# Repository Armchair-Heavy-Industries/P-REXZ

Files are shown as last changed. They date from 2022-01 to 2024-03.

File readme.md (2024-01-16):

# P-REXZ
The P-REXZ is a cantilevered CoreXZ 3D Printer with a polar bed. 

The current state of the project is as follows:
Mechanically, the printer is functional and prints. Currently honing in printability and ease of assembly. A more capable Polar/PolarXZ kinematic type has been added to klipper, and optimization still needs to be done.

Project Leads: Derpimus, Corvid, and Bwnance

Join me on Discord (https://discord.gg/armchairengineeringsux)

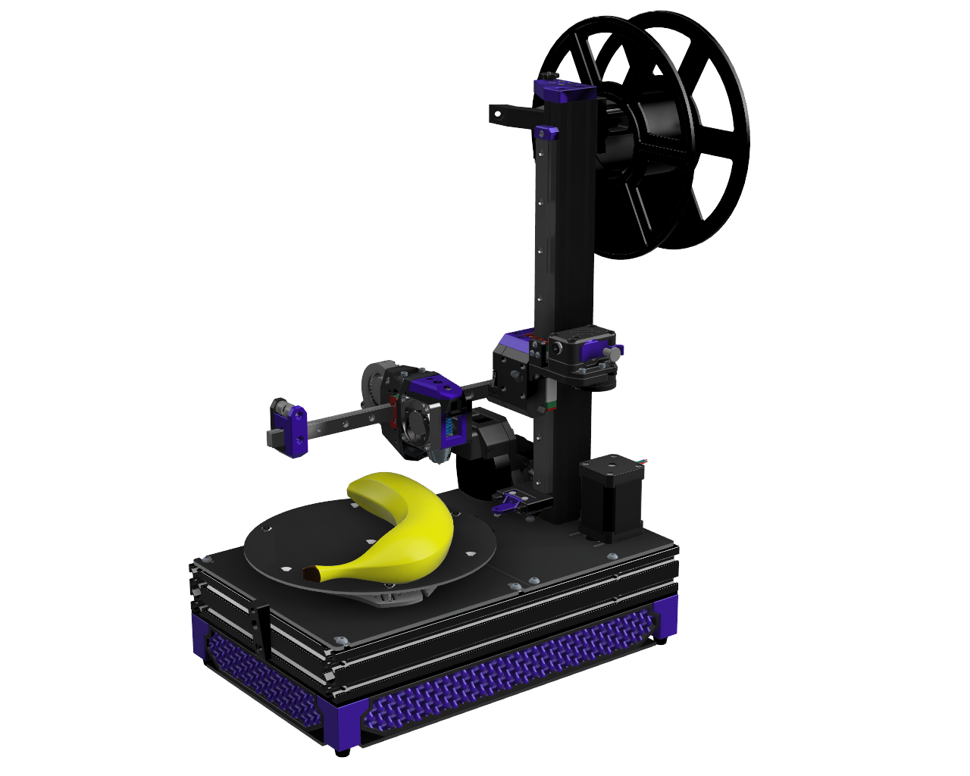
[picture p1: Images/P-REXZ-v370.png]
Image of the P-REXZ


Thank you for T-Laser for the belt path inspiration https://github.com/FiCacador/Tlaser

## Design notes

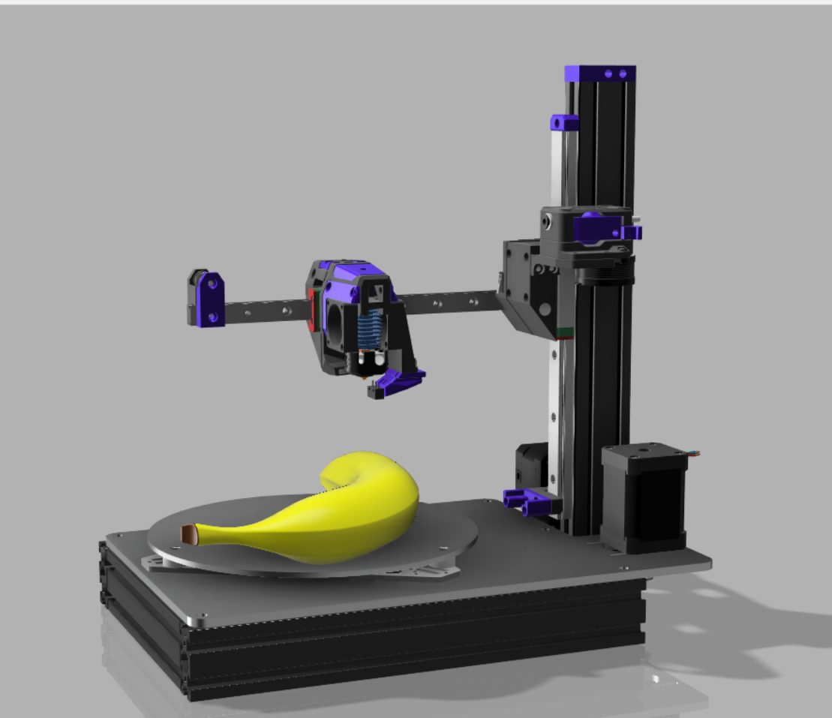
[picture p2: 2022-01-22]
Images/PREXZ.png

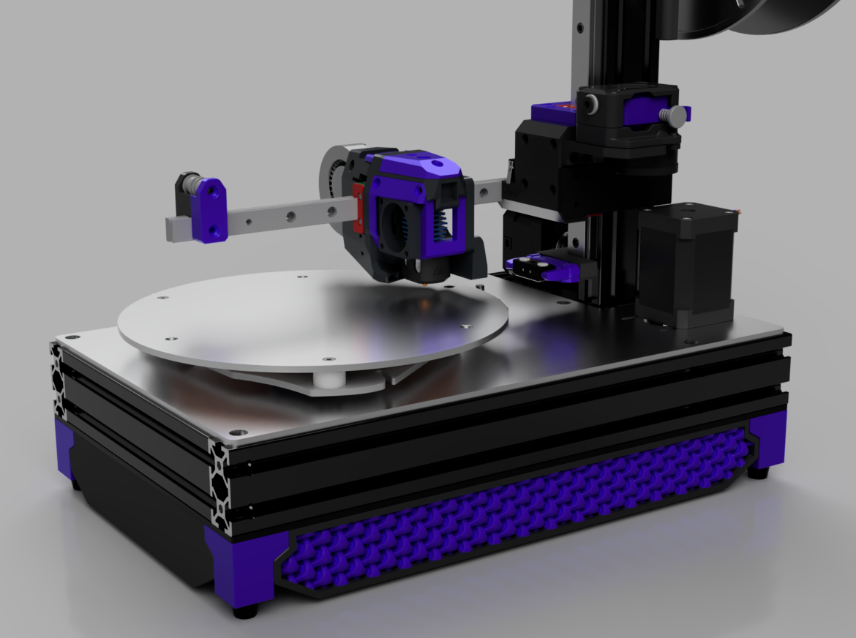
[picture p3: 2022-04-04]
Images/P-REXZ-V247.png

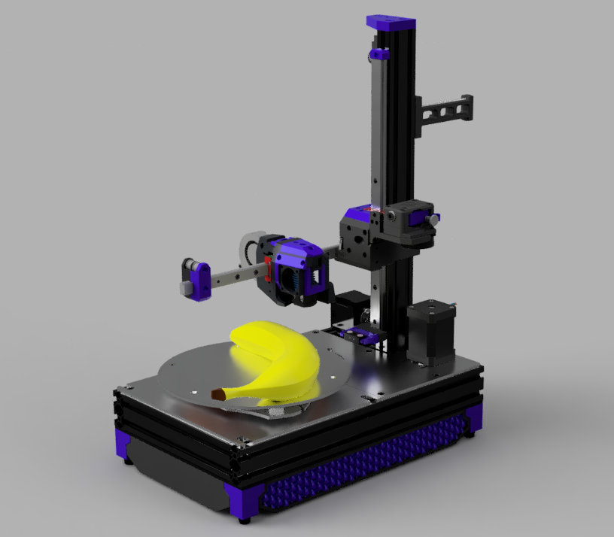
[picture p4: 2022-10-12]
Images/P-REXZ-V274.png

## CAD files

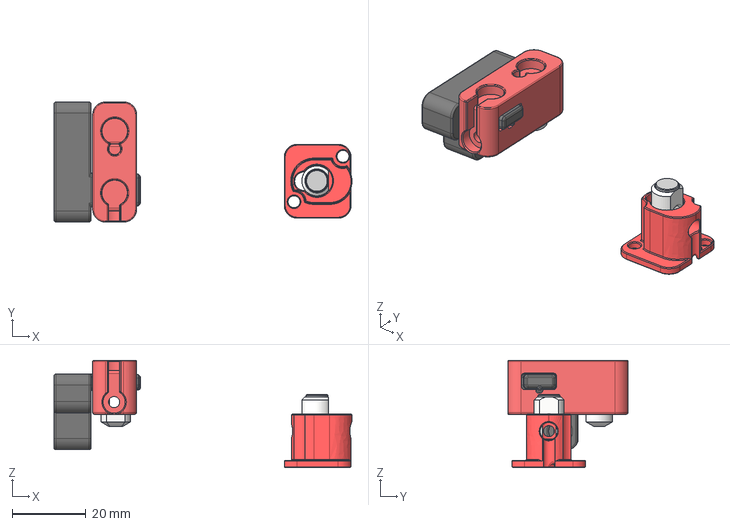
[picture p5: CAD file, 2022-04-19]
CAD/Prexz unklicky 01 v1.step
80.6 x 32.5 x 29.0 mm
Probe Dock v2
z endstop

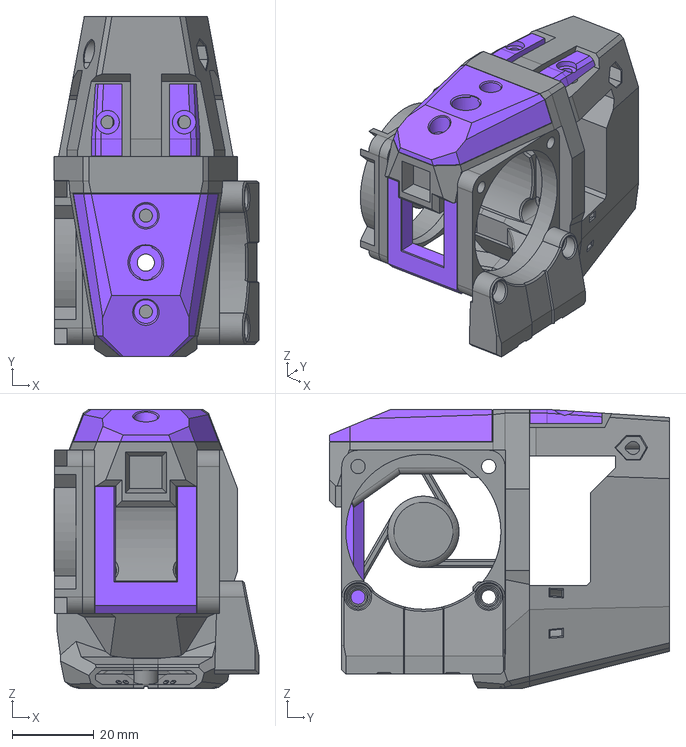
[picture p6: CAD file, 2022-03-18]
CAD/Toolhead/Toolhead V1 - Rapido.step
50.2 x 83.3 x 68.4 mm

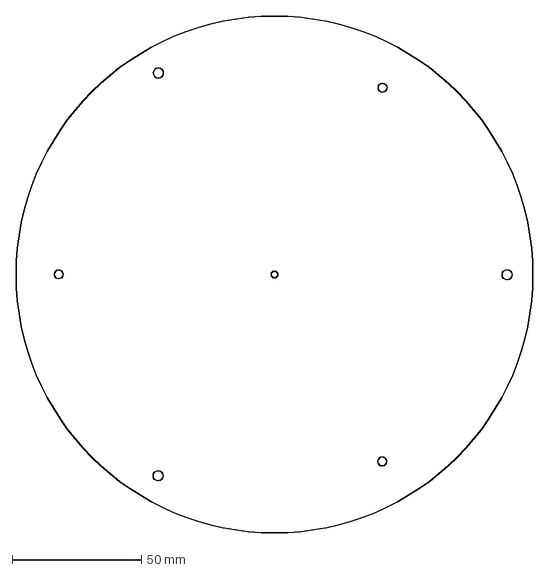
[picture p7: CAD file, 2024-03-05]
DXF+Drawings/Bed/Bed.dxf
200.0 x 200.0 mm

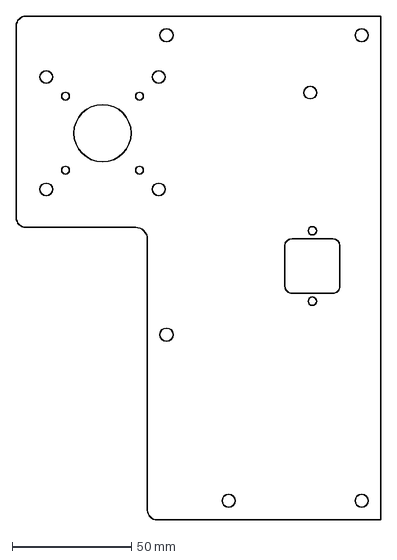
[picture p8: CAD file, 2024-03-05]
DXF+Drawings/BedPlates/BedPlate2.dxf
152.7 x 211.0 mm

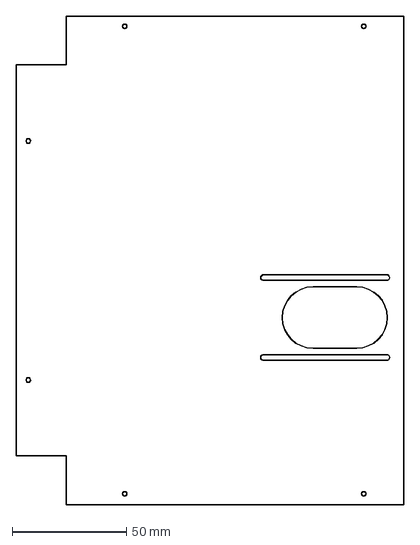
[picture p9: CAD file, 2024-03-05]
DXF+Drawings/ElectronicsPlates/LowerElectronicsPlate1.dxf
169.7 x 214.2 mm

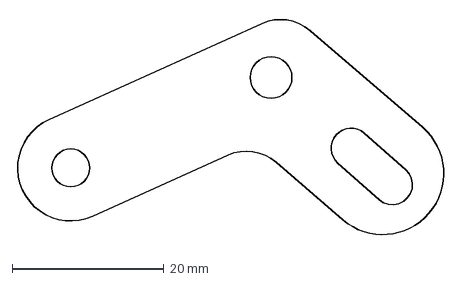
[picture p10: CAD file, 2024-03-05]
DXF+Drawings/Frame+misc/TensionerBone[x2].dxf
57.4 x 29.8 mm

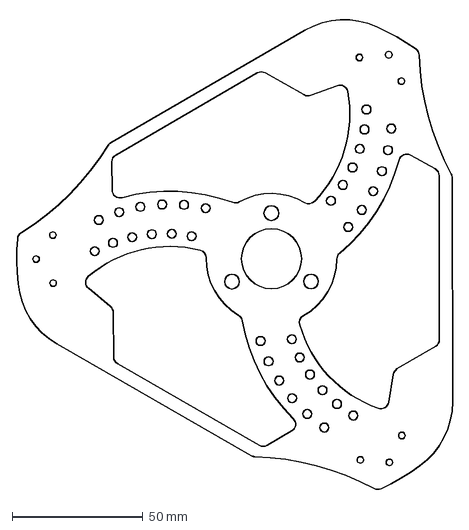
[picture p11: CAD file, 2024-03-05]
DXF+Drawings/Mallninja/MallNinja.dxf
166.8 x 181.1 mm

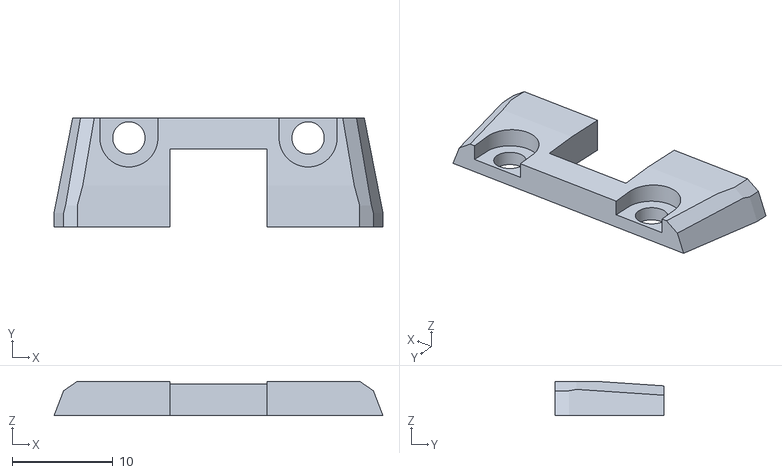
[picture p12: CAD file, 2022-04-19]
STLs/Toolhead/Dragonfly BMO/[a]_V1 - UniClamp.stl
32.6 x 10.8 x 3.40

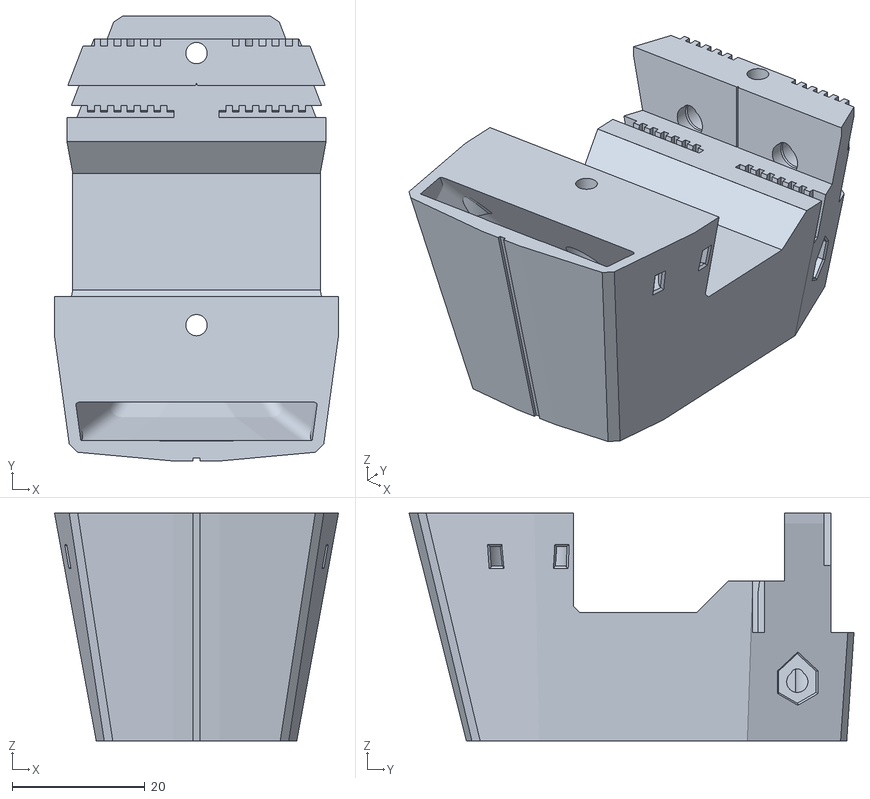
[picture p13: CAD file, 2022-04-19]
STLs/Toolhead/Rapido/V1 - Print Fan Mount.stl
42.8 x 67.0 x 34.3

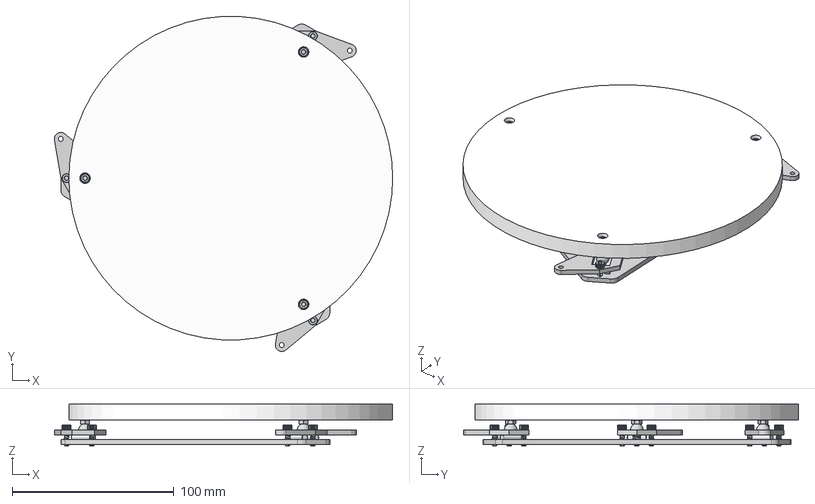
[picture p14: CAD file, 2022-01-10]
CAD/Mall Ninja Bed.step
209.0 x 206.9 x 25.9 mm
91292A114_18-8 Stainless Steel Socket Head Screw x 3
90592A085_Steel Hex Nut x 3
1598K29_Hardened Bearing-Quality 440C Stainless Steel Ball x 3
4mm diameter rod x 6
90751A112_18-8 Stainless Steel Socket Head Screws x 9

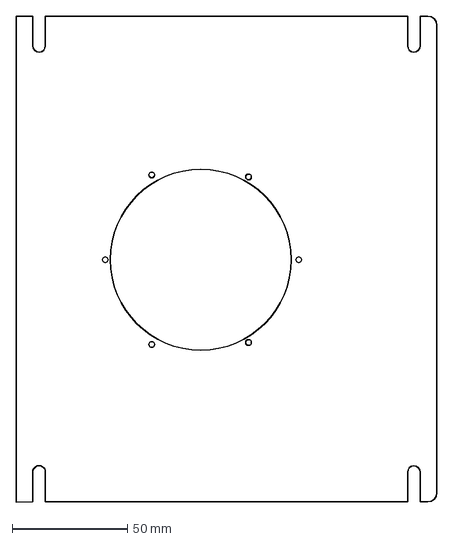
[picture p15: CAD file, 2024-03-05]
DXF+Drawings/BedPlates/BedPlate1.dxf
182.8 x 211.0 mm

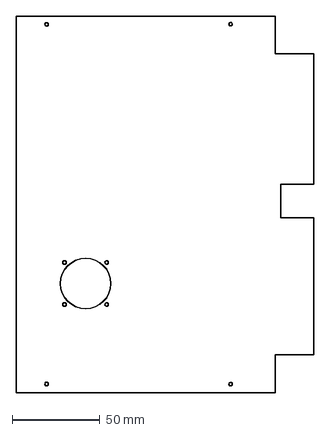
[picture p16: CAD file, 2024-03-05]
DXF+Drawings/ElectronicsPlates/LowerElectronicsPlate2.dxf
169.7 x 214.2 mm

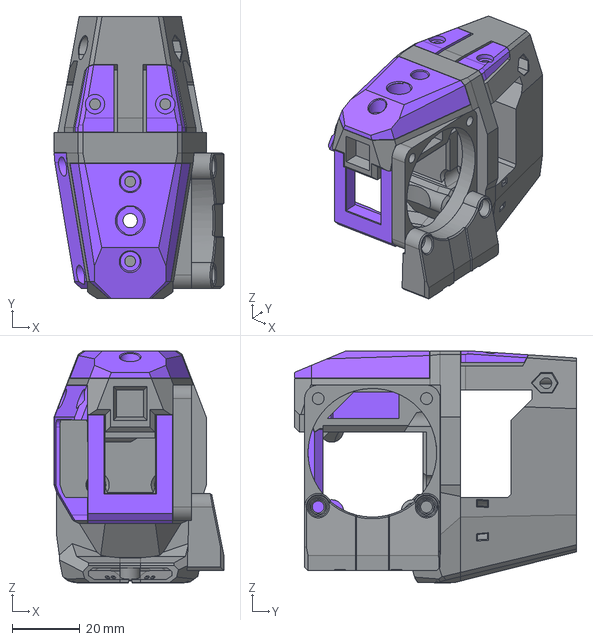
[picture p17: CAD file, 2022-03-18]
CAD/Toolhead/Toolhead V1 - Dragonfly BMO.step
50.2 x 83.3 x 68.4 mm

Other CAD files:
CAD/Toolhead/Toolhead V1 - Revo.step
DXF+Drawings/ElectronicsPlates/UpperElectronicsPlate.dxf
STLs/Toolhead/Dragonfly BMO/V1 - 4007 Grill.stl
STLs/Toolhead/Dragonfly BMO/V1 - Air Guide-Face - 3010.stl
STLs/Toolhead/Dragonfly BMO/V1 - Dragonfly BMO - Hotend Mount.stl
STLs/Toolhead/Dragonfly BMO/V1 - Klicky Mount.stl
STLs/Toolhead/Dragonfly BMO/[a]_V1 - 3010 Speed Fairing.stl
STLs/Toolhead/Dragonfly BMO/[a]_V1 - DD Mount Cap.stl
STLs/Toolhead/Rapido/V1 - 4007 Fan - 3mm Spacer.stl
STLs/Toolhead/Rapido/V1 - 4007 Grill.stl
STLs/Toolhead/Rapido/V1 - Klicky Mount.stl
STLs/Toolhead/Rapido/V1 - Rapido - Hotend Mount - V1.stl
STLs/Toolhead/Rapido/[a]_ V1 - DD Mount Cap.stl
STLs/Toolhead/Rapido/[a]_Rapido - V1 - Air Guide-Face.stl
STLs/Toolhead/Revo/V1 - 4007 Grill.stl
STLs/Toolhead/Revo/V1 - Air Guide-Face - 3010.stl
STLs/Toolhead/Revo/V1 - Klicky Mount.stl
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

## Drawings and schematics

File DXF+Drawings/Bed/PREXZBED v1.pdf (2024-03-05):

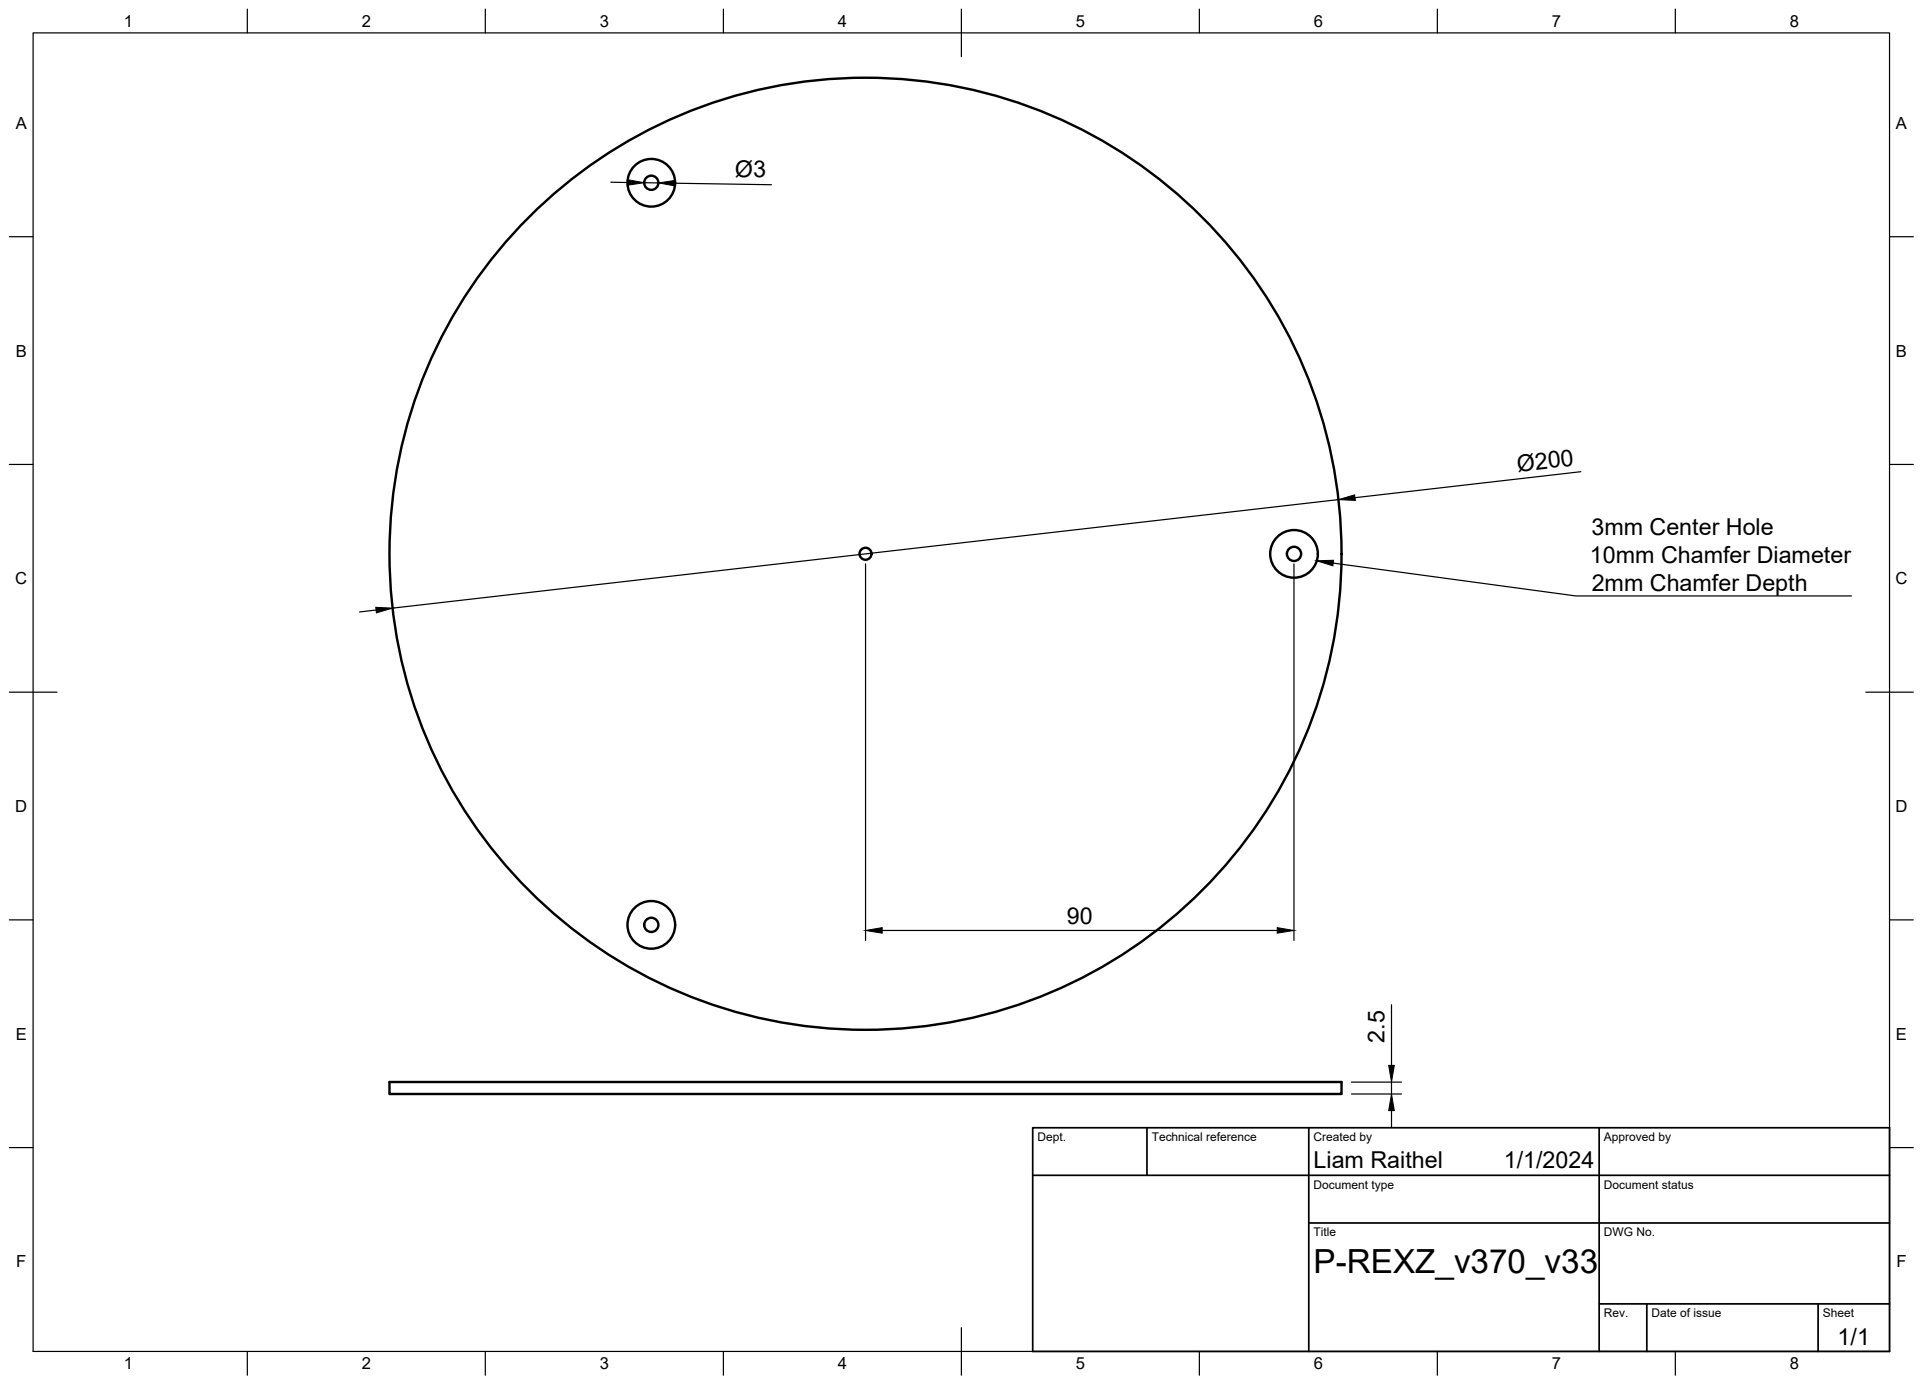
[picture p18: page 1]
Title; DWG No.; Rev.; Date of issue; Sheet; Liam Raithel 2.5; 3mm Center Hole 10mm Chamfer Diameter 2mm Chamfer Depth

Dept. | Technical reference | Created by 1/1/2024 | Approved by

Document type | Document status

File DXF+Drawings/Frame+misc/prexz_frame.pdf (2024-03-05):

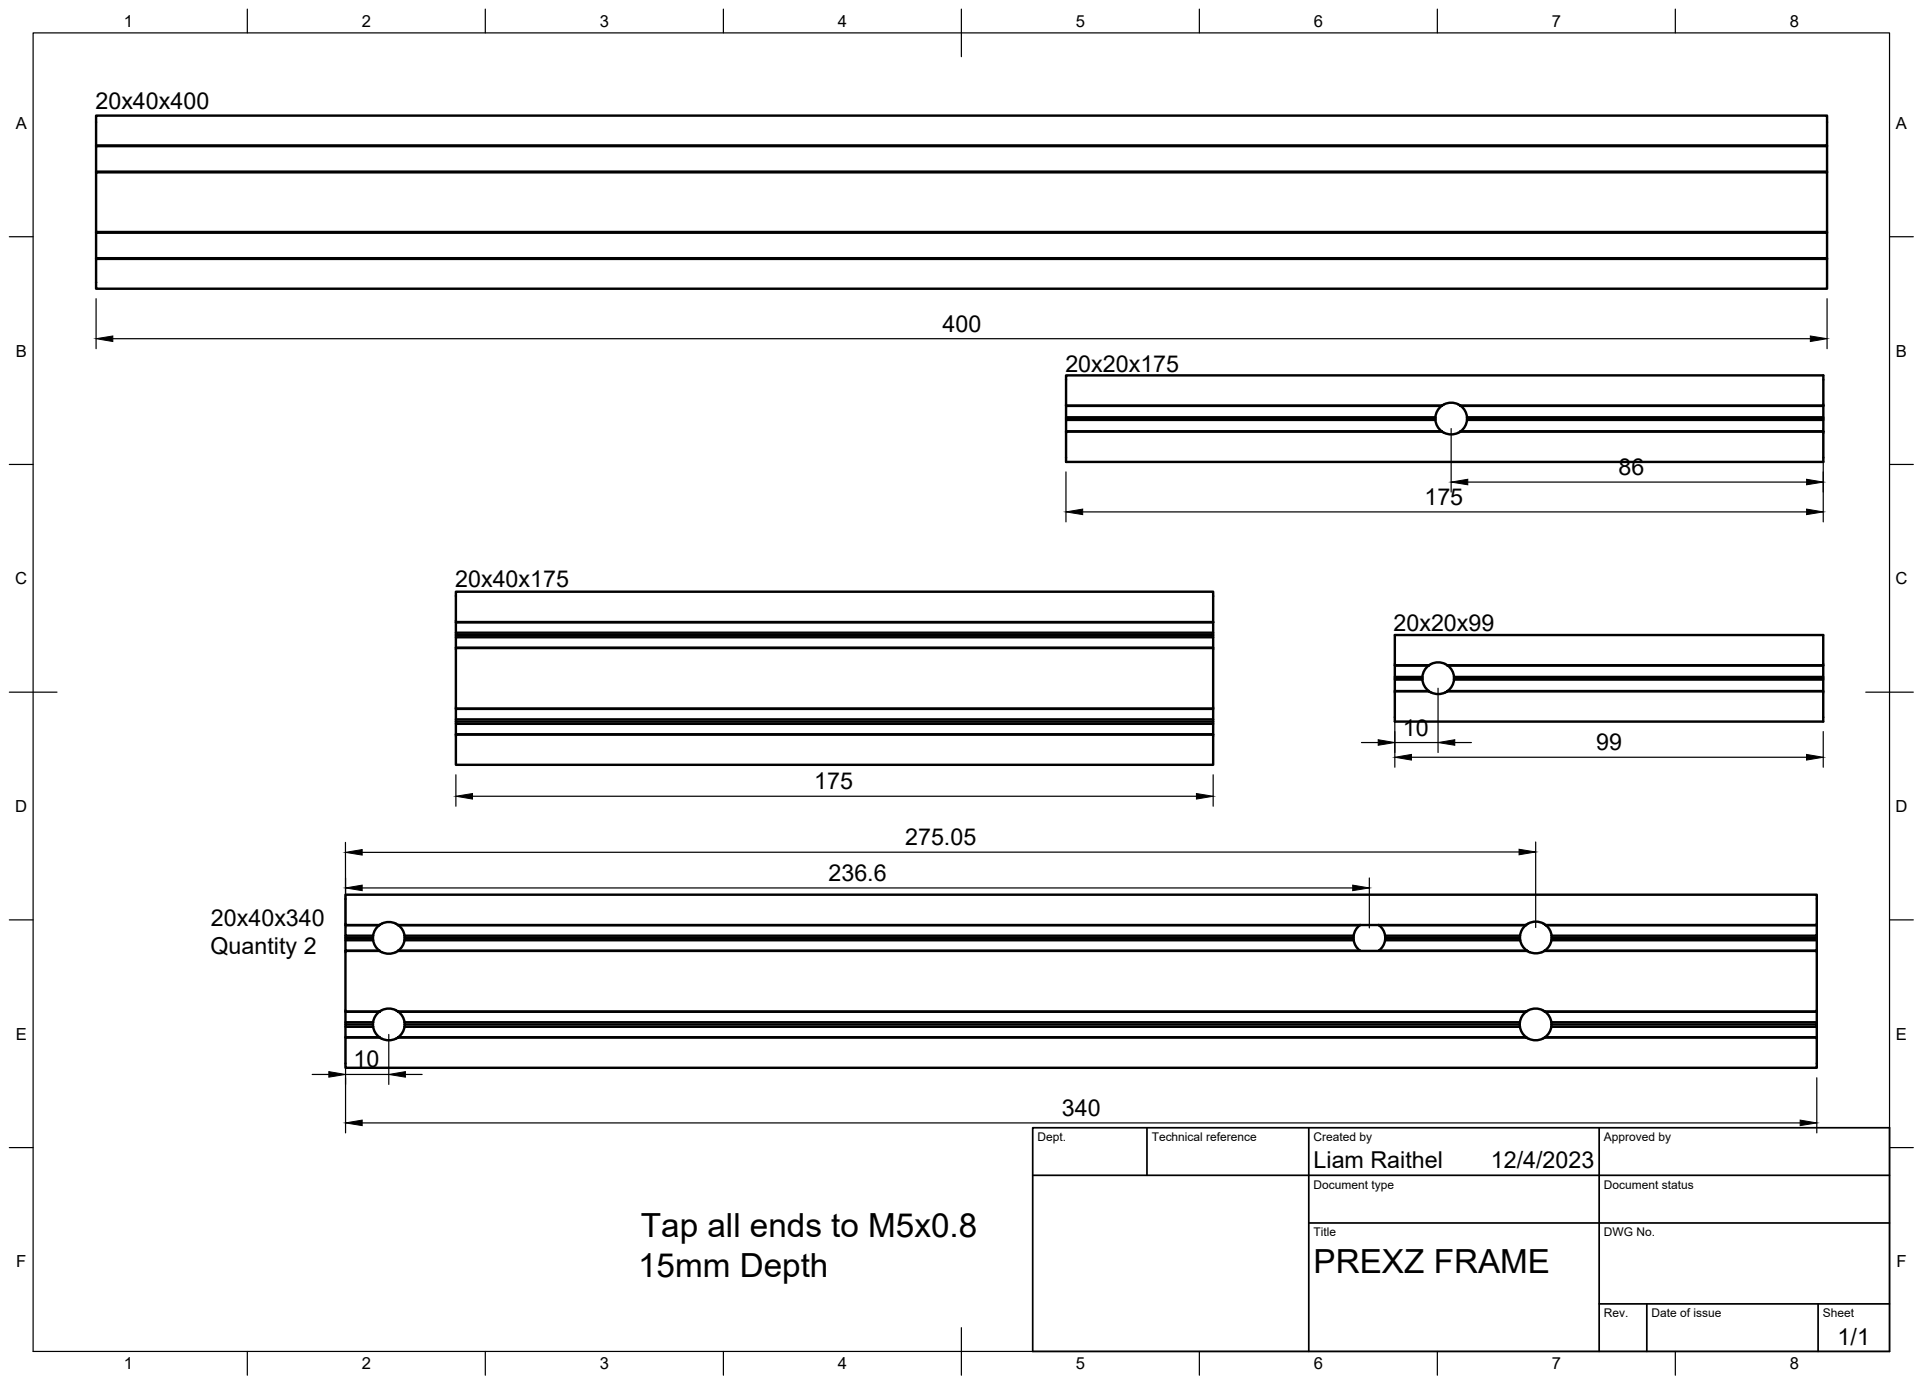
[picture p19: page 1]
Title; DWG No.; Rev.; Date of issue; Sheet; PREXZ FRAME; Quantity 2

Dept. | Technical reference | Created by Liam Raithel 12/4/2023 | Approved by

Document type | Document status

Tap all ends to M5x0.8
15mm Depth

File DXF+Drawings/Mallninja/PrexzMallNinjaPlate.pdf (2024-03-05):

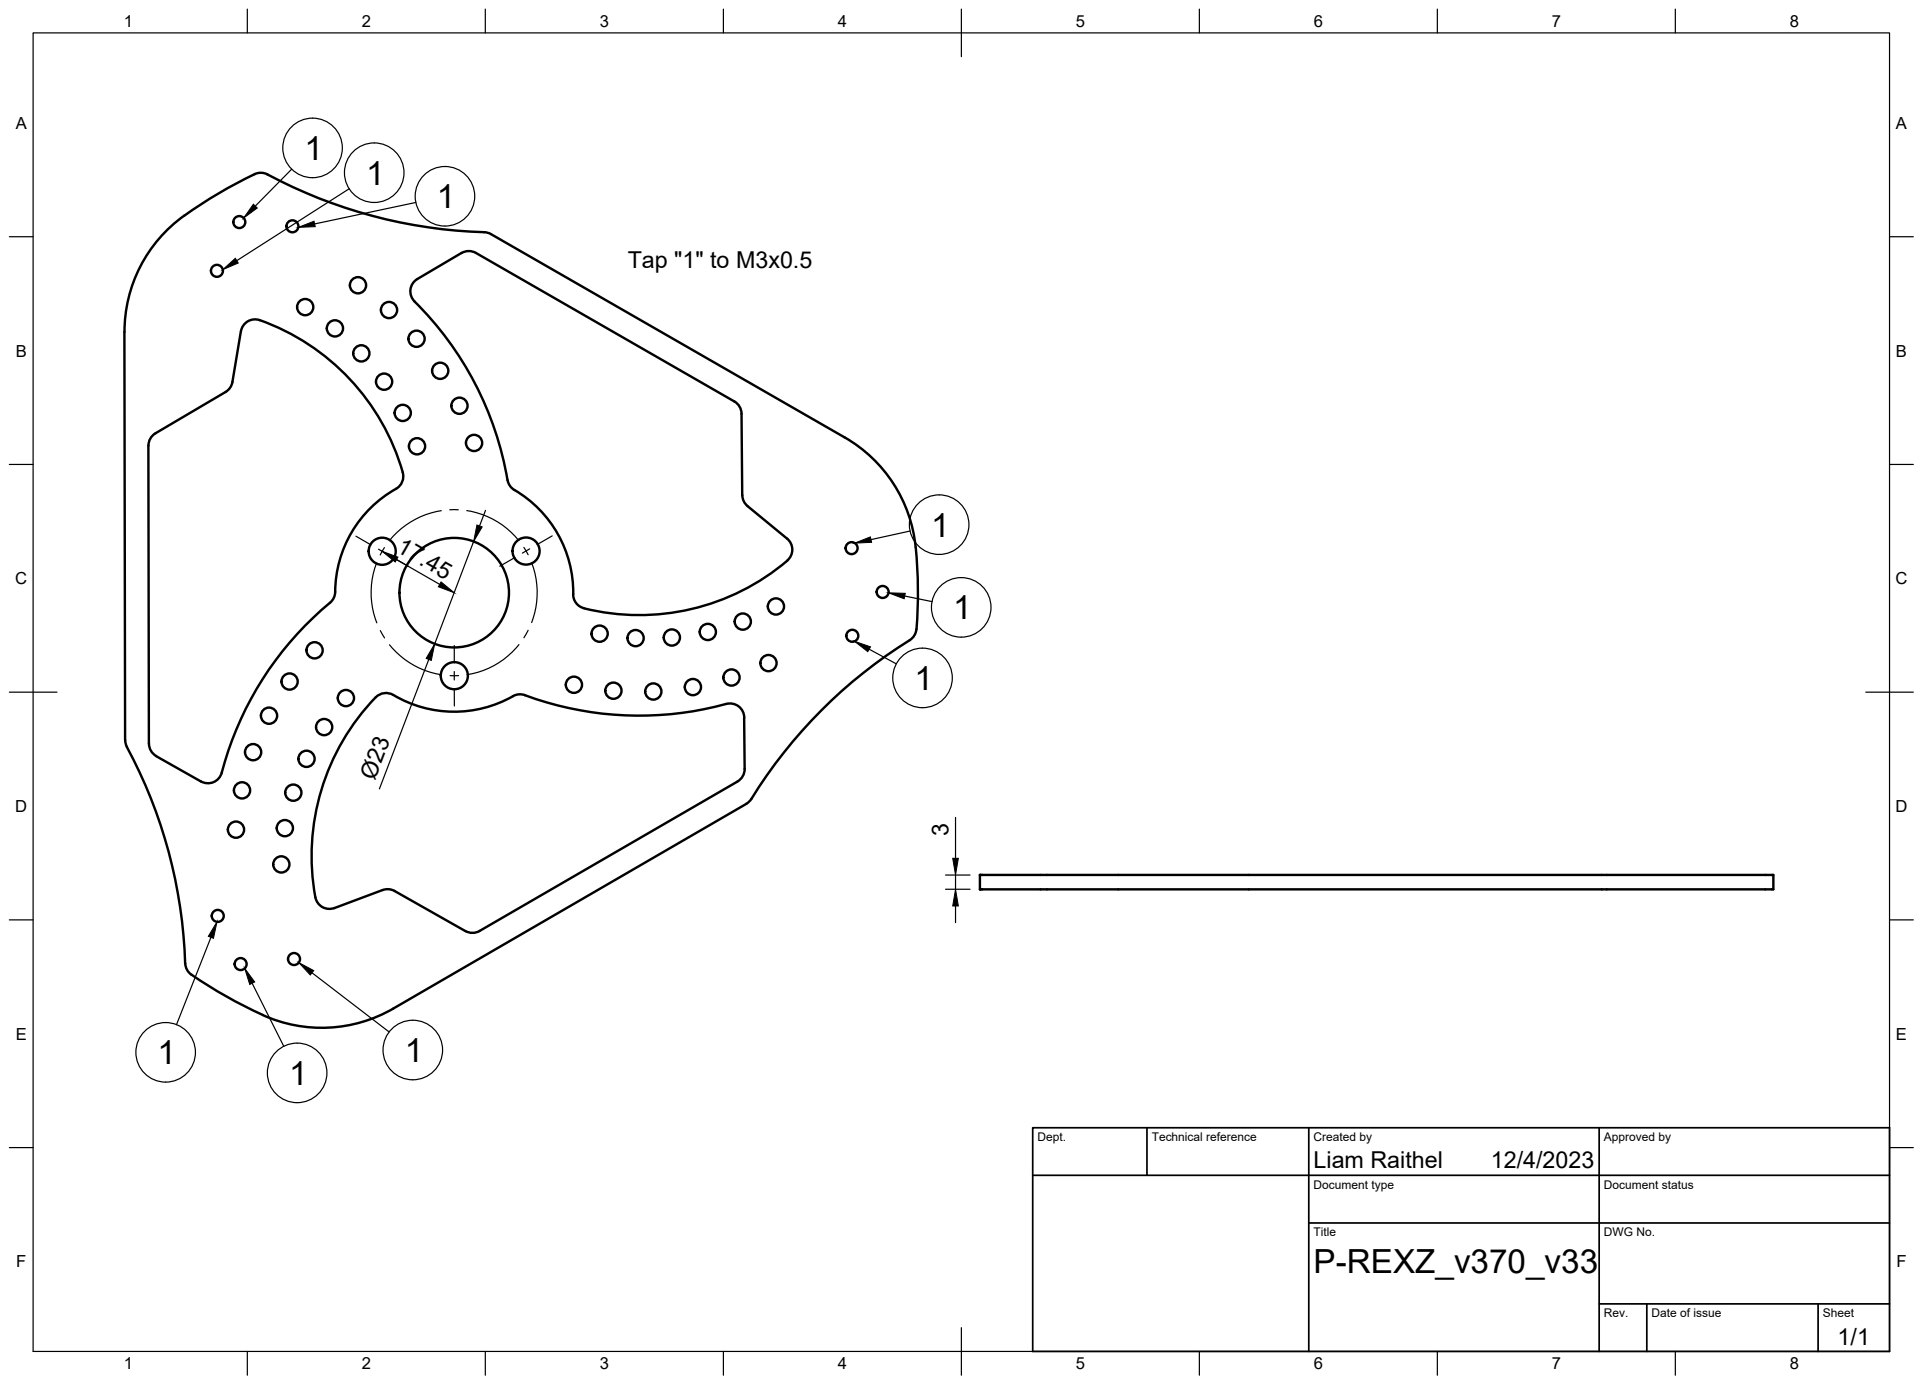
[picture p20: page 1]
Title; DWG No.; Rev.; Date of issue; Sheet; Tap "1" to M3x0.5

Dept. | Technical reference | Created by Liam Raithel 12/4/2023 | Approved by

Document type | Document status

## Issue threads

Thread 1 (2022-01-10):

X and Z Homing

CorvidBuilds, 2022-01-10:
Design spec as of now is Klicky for Z homing.
Will X homing be sensorless, microswitch endstop, or hall effect?

lraithel15133, 2022-01-11:
I am a fan of sensorless homing but plan to provision for X endstop in the XZ joint

Closed 2022-10-12.

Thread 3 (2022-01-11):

New Toolhead

lraithel15133, 2022-01-11:
A new toolhead should be designed so that the X rail can be rotated 90 degrees into the ideal orientation; we can possibly shed some weight and have a 5015 part fan as well. Open to most hotend options at this time, revo and mosquito(fslice) are too pricey probably.

New toolhead should be designed for mgn12, but hopefully also easily modified for mgn9.
Bowden is preferred for me personally, but I am open to direct drive if we can get some solid weight numbers comparing equivalent toolheads in terms of features.
We are speccing a klicky probe at this time. It must have 0 Y probe offset. Minimal X offset is preferred, and its better if its on the Z axis side of the hotend, or in the middle (magnets to the carriage parts, centering switch under the nozzle with only z offset)

CorvidBuilds, 2022-01-11:
Work in progress

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

CorvidBuilds, 2022-01-12:
# Not quite full-featured yet but the shapes are there.
The STEP has been uploaded.
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

CorvidBuilds, 2022-01-13:
# Thanks Derp
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

CorvidBuilds, 2022-01-13:
# Belt Clamping
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

CorvidBuilds, 2022-01-14:
Hotends supported:
- Dragonfly BMO (rigid mount)
- Dragonfly BMS (don't like it, will probably trash)
- Rapido (rigid mount)
  - Move fan up
  - New fairings
- Dragon (rigid mount)
  - with some modification

CorvidBuilds, 2022-01-30:
# Hotend Fan Testing
4007:
- ~1.5 m/s airflow unobstructed
- ~1.0 m/s airflow pushing through the Dragonfly BMO mount
- Sounds decently quiet
- Hand test suggests significant airflow losses forward out of the front of the toolhead
3007:
- [TBD] airflow unobstructed
- [TBD] airflow pushing through the Dragonfly BMO mount
- Sounds decently quiet
- Hand test suggests some airflow losses forward out of the front of the toolhead

CorvidBuilds, 2022-04-04:
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

CorvidBuilds, 2022-04-04:
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

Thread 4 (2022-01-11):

Polar + CoreXZ Klipper Kinematics Module

lraithel15133, 2022-01-11:
https://github.com/Klipper3d/klipper/blob/master/klippy/kinematics/corexz.py
https://github.com/Klipper3d/klipper/blob/master/klippy/kinematics/polar.py
https://github.com/Klipper3d/klipper/blob/master/klippy/chelper/kin_polar.c
https://github.com/Klipper3d/klipper/blob/master/klippy/chelper/kin_corexz.c

Some serious brain power will be needed to combine these two modules so that we can use both CoreXZ and Polar at the same time

lraithel15133, 2022-01-12:
#include <math.h> // sqrt
#include <stdlib.h> // malloc
#include <string.h> // memset
#include "compiler.h" // __visible
#include "itersolve.h" // struct stepper_kinematics
#include "trapq.h" // move_get_coord

static double
polar_stepper_radius_calc_position(struct stepper_kinematics *sk, struct move *m
                                   , double move_time)
{
    struct coord c = move_get_coord(m, move_time);
    return sqrt(c.x*c.x + c.y*c.y);
}

static double
corexz_stepper_plus_calc_position(struct stepper_kinematics *sk, struct move *m
                                  , double move_time)
{
    struct coord c = move_get_coord(m, move_time);
    return polar_stepper_radius_calc_position + c.z;

}

struct stepper_kinematics * __visible
polarxz_stepper_alloc(char type)
{
    struct stepper_kinematics *sk = malloc(sizeof(*sk));
    memset(sk, 0, sizeof(*sk));
    if (type == 'x')
        sk->calc_position_cb = corexz_stepper_plus_calc_position;
    return sk;
}

Sam-Apostel, 2022-12-13:
I tried to implement this about a year ago but couldn't get the homing sequence right. I wasn't able to run the tests on my machine and waiting for github actions each time was a no go for me at the time.

I'll leave my attempt here in the hope for a combined successful kinematics module.
https://github.com/Klipper3d/klipper/compare/master...Sam-Apostel:klipper:master

lraithel15133, 2022-12-13:
>

Hi! You should join our discord. Kinematics are working currently and we just have to optimize them
https://discord.gg/ZTdFpCNm.

Closed 2022-12-13.

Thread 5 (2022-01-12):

Bed Centering Toolhead

lraithel15133, 2022-01-12:
Small ~2.5mm hole in the middle of either the bed (small hole in the magnet as well) which is used to aid in centering the bed during assembly.
Will either have a m2 or m3 bolt on the end, or even just a nozzle as a tip.
Centering toolhead will be installed, then put to 0,0 position in printer control. Lower z axis to slot nozzle/bolt into centering hole with the bed loose. Then, tighten the bed with the center at true 0,0 position.

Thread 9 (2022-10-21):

Skirts fastener incompatibility

CorvidBuilds, 2022-10-21:
We took the skirts from Voron V0 but put a 3mm acrylic plate between the skirt and the frame. I suggest removing the inset geometry for the screw heads to allow the use of M3x12s.
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

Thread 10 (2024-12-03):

Where can I find information about the firmware?

csscsccs, 2024-12-03:
Where can I find information about the firmware? I didn't find information about polarXZ in the printer config folder of klipper.

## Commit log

2022-01-09 created CAD folder
2022-01-10 Add files via upload
    Added extruder, hotend, AB tensioner, moved motor to the bottom, added AB idler.
2022-01-10 Work In progress Polar bed kinematics
    [Polar bed WIP.f3d]
2022-01-10 Initial Mall Ninja Shit commit
    [Mall Ninja Bed.step]
2022-01-10 Added motor mount and Needle tray mount
    [Moron Mini v11.f3d]
2022-01-11 First complete draft
    [Polar Bed First Draft .f3d]
2022-01-12 Add files via upload
    Modified the motor mount to help printability, thinned out the non-structural slip ring member.
2022-01-12 Create P-REXZ Toolhead.step
    [P-REXZ Toolhead.step]
2022-01-14 Add files via smart microwave
    Complete redesign of bed mounting system using 78x60x10 bearing.
2022-01-14 Add files via Samsung Smart Refrigerator
    Updated CAD with bed. Toolhead coming, and frame layout will be finalized at some point
2022-01-18 Updated Toolhead STEP
    [P-REXZ Toolhead.step]
2022-02-02 Updated toolhead to latest
    Rapido, printability improvements, better hotend air flow, ECAS04 placement rough, klicky offset
2022-02-09 Update Toolhead - Rapido.step
2022-03-18 Updated Toolhead to V1
    [Toolhead V1 - Dragonfly BMO.step, Toolhead V1 - Rapido.step, Toolhead V1 - Revo.step]
2022-03-19 Added Toolhead STLs
    [Dragonfly BMO - V1 - Hotend Mount.stl, Rapido - V1 - 4007 Fan - 3mm Spacer.stl, Rapido - V1 - 4007 Grill.stl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]
2022-03-19 Changed some formatting
    [V1 - 4007 Fan - 3mm Spacer.stl, V1 - 4007 Grill.stl, V1 - Dragonfly BMO - Hotend Mount.stl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]
2022-04-08 Better ball bearing model
    Just to remove that dummy placeholder and using a proper 6812 metric ball bearing model, from McMaster-Carr's site.
2022-04-19 Revised belt clamping
    [V1 - Print Fan Mount.stl, V1 - Revo Micro - Hotend Mount.stl, [a]_V1 - Belt Clamp 1.stl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]
2022-06-29 Add files via upload
    Most significant changes are adding a Z chain mount, and significant XZJoint bracing.
2022-10-12 Minor changes
    2 piece bed plate from DustinSpeed, replacement models from vinny and various other small adjustments
2024-03-05 Upload DXFs an Drawings
    [Bed.dxf, BedPlate1.dxf, BedPlate2.dxf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]
